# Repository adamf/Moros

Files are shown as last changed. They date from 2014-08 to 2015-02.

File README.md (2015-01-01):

Moros
=====

Moros is an Arduino-based game clock.

This project provides all the components needed to build the case, electronics
and software for a game clock. 

Features
--------
* Large, easy to read numbers
* Graphical display of flag (currently the flag of the USSR)
* Durable arcade buttons for clock buttons
* Extensible & open design, including the case, electronics and software (MIT License)
* Built by avid blitz chess players

Software
========

The Moros software is written in C++ for the Arduino microcontroller platform. The software
was built for the Arduino Uno and Arduino Micro. The software was built and tested on Ubuntu 14.04,
but should build for any platform with small changes to the Makefile.

For Ubuntu 14.04, the packages required can be installed with:

    sudo apt-get update && apt-get install arduino arduino-code arduino-mk

And then to build & install on the microcontroller:

    cd moros
    make upload

We also provide serial port debug output (this starts screen(1), quit with ctrl-a k):

    make upload monitor

Case
====

The case model is built with OpenSCAD, then exported into SketchUp for splitting into 3D-printable format.

Shield
======

See the README.md file in the shield/ directory in this repository.

TODO
====
* Support displaying hours
* Re-add displaying 10th of a second
* Update case to reflect use of arcade-style buttons
* Update case to reflect the reset button
* Update shield to reflect reset button to ground, not VCC
* Clean up case SCAD code, and add README and Makefile for generation of 3D-printable models
* Support saving the time between reboots

Copyright 2014 Adam Fletcher and Matt Zimmerman

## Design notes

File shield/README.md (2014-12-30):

Moros Arduino Micro Shield
==========================

This is the [KiCad](http://www.kicad-pcb.org) project for the Arduino Micro
shield used to build the Moros chess clock. This shield makes it much easier
to attach the OLED screens and buttons to the Arduino in a compact format
suitable for shoving inside the Moros case.

To use this project you need the latest version of KiCad, or a version
built from head after December 28th, 2014. In Ubuntu it is easiest to add
the [KiCad PPA](https://code.launchpad.net/~js-reynaud/+archive/ubuntu/ppa-kicad) and
install KiCad from there. You'll need to set the KIGITHUB environment variable:

    export KIGITHUB='https://github.com/kicad'

Otherwise KiCad won't find its component libraries.

Three other component libraries are required for this project, from two different repositories:

* ab2_header and ab2_idc from [AB2's KiCad Library set](https://github.com/ab2tech/KiCad)
* arduino_micro_shield from [Adam Fletcher's Arduino Micro Shield Component & Footprint](https://github.com/adamf/arduino_micro_shield)

Both are included in this source tree for convenience. 

Opening the moros.pro file in KiCad will load all needed files. From there the schematic can be edited, 
a netlist generated, and a PCB laid out. The PCB in this repo is suitable for export to Gerber format files.
In order to send those Gerber format files to the preferred fab, [OSH Park](http://oshpark.com), the Gerber
files output by KiCad must be renamed:

    cd gerber
    bash rename_and_zip.sh

The resulting .zip file can be uploaded to OSH Park for fabrication.

Copyright 2014 Adam Fletcher and Matt Zimmerman

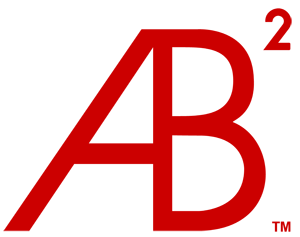
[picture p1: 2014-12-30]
shield/KiCad/3d_models/ab2_meshconv_gui/AB2Tech_300.png

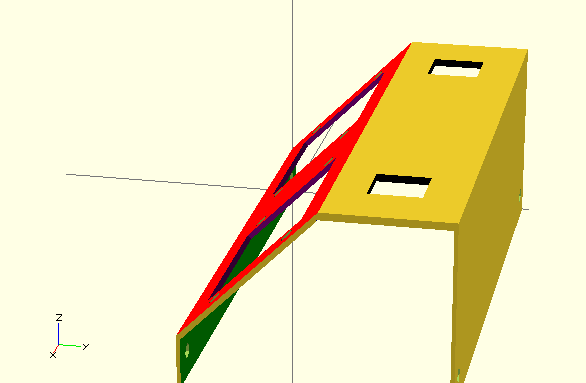
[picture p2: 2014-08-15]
case/case.png

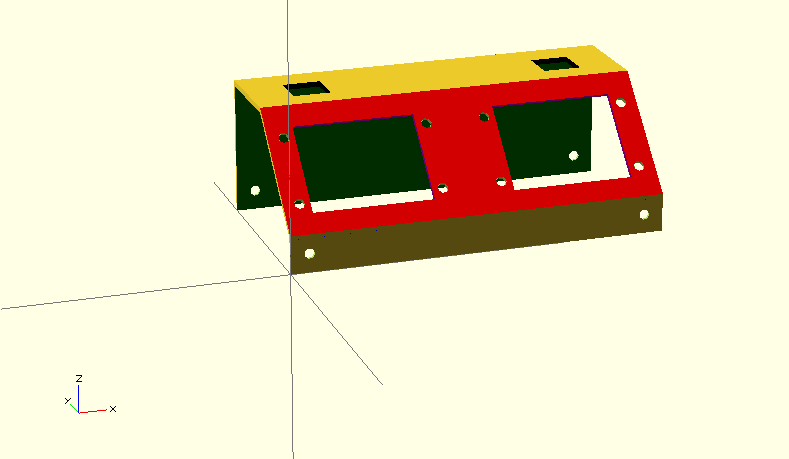
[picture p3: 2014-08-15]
case/clock_outer_case.png

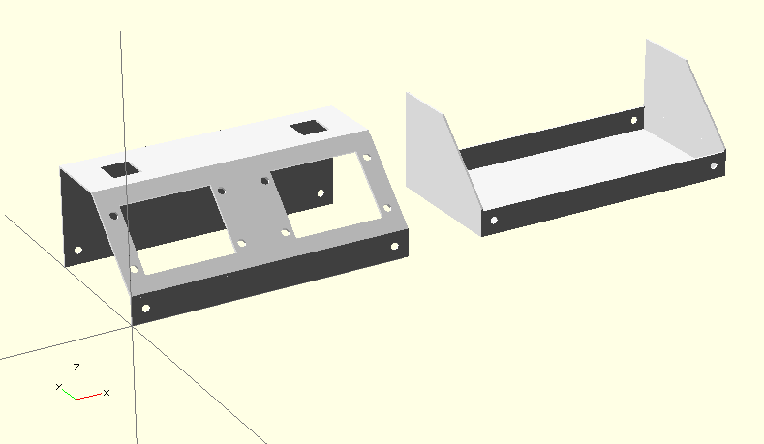
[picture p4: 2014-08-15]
case/case_scad.png

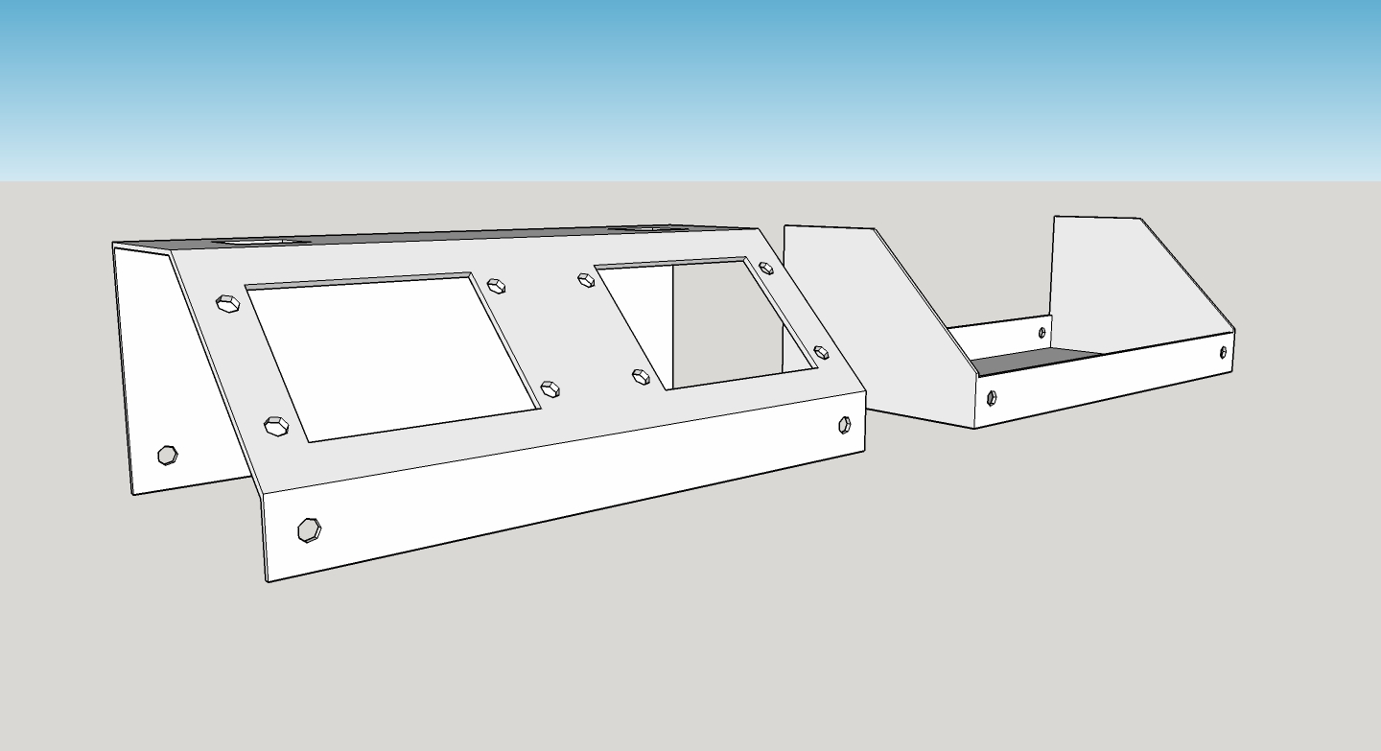
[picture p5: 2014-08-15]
case/case_sketchup.jpg

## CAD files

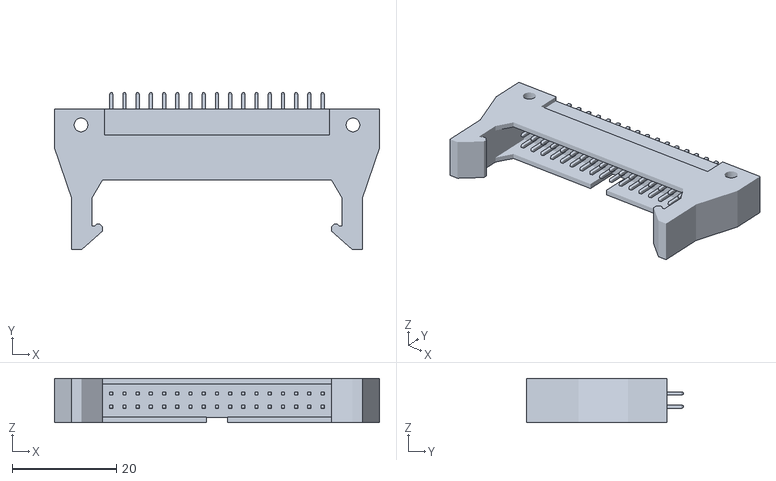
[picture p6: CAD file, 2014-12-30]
shield/KiCad/3d_models/ab2_idc/stl/AB2_HDR_M17-2V-S-OMRON_COMPLETE.stl
62.5 x 30.2 x 8.50

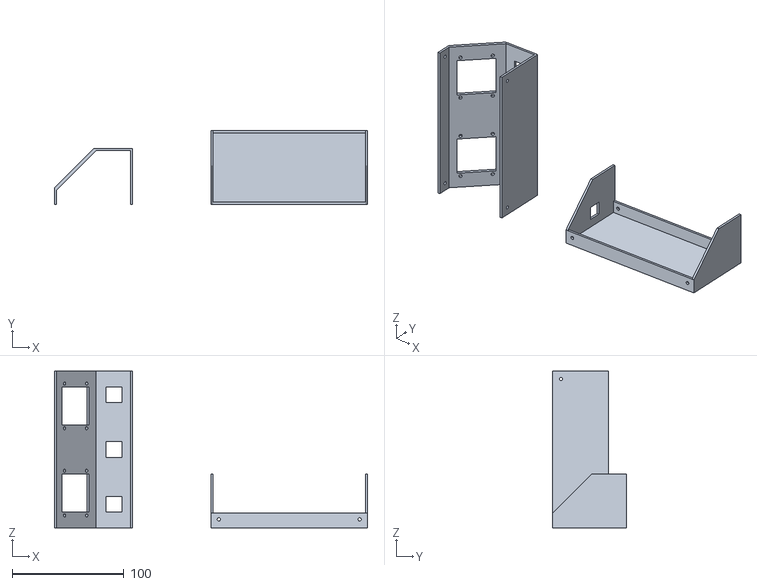
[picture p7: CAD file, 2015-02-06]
case/case.stl
280.0 x 66.0 x 140.0

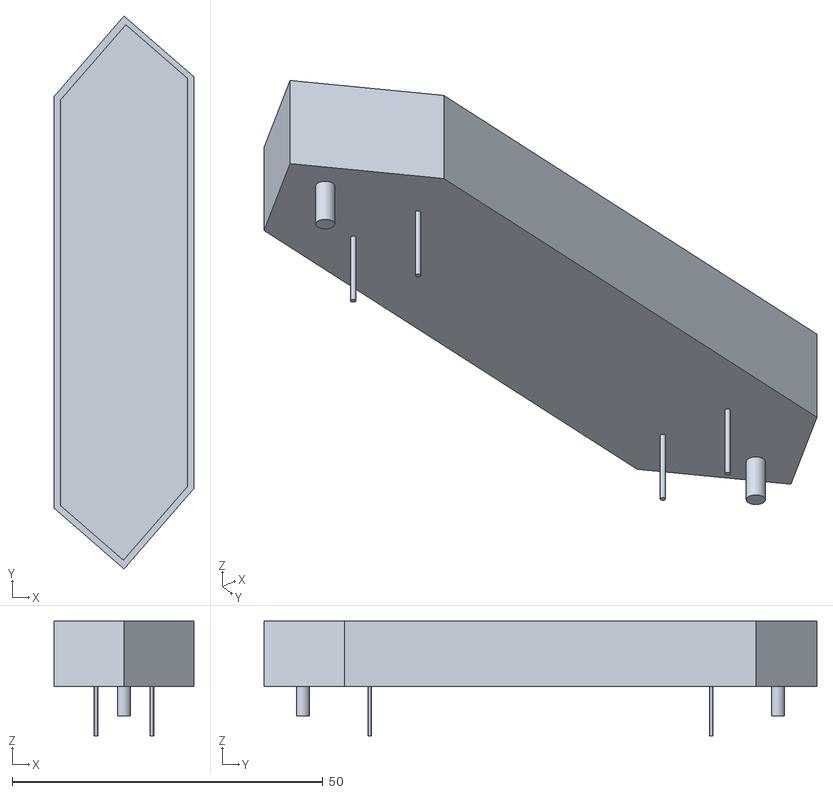
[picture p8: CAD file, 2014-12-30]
shield/KiCad/3d_models/ab2_7seg/stl/AB2_7_SEG_8IN_V_WINGS3D.stl
22.5 x 89.0 x 18.5

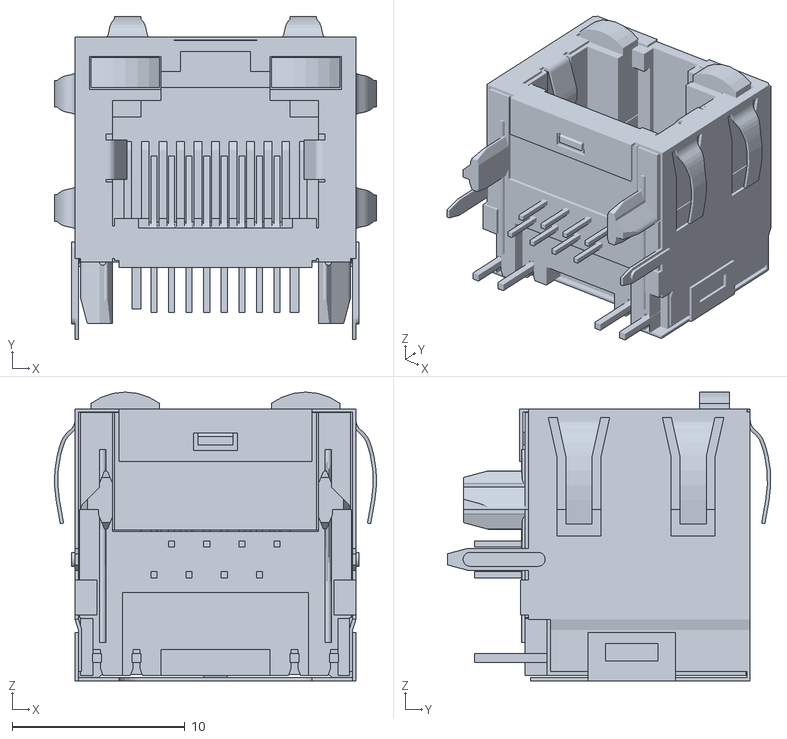
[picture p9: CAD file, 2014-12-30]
shield/KiCad/3d_models/ab2_connector/stl/AB2_RJ45_RA_LEDS.stl
18.6 x 18.7 x 16.7

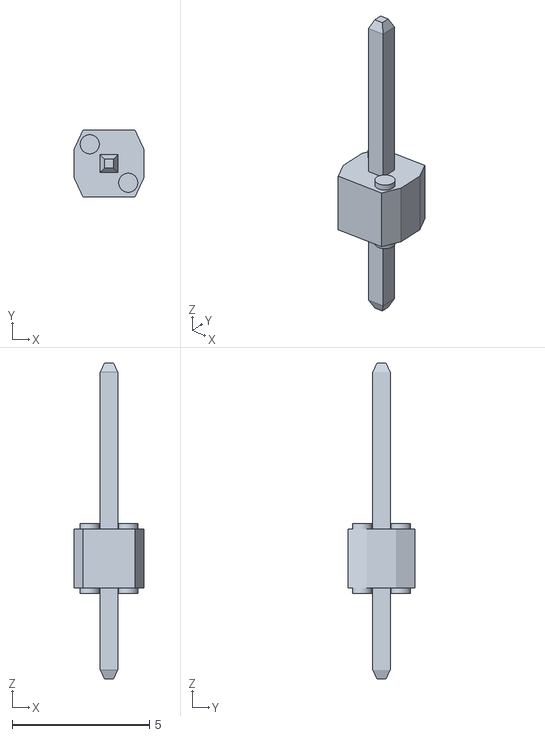
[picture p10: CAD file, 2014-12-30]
shield/KiCad/3d_models/ab2_header/stl/AB2_HDR_M01-1V_WINGS3D.stl
2.54 x 2.42 x 11.5

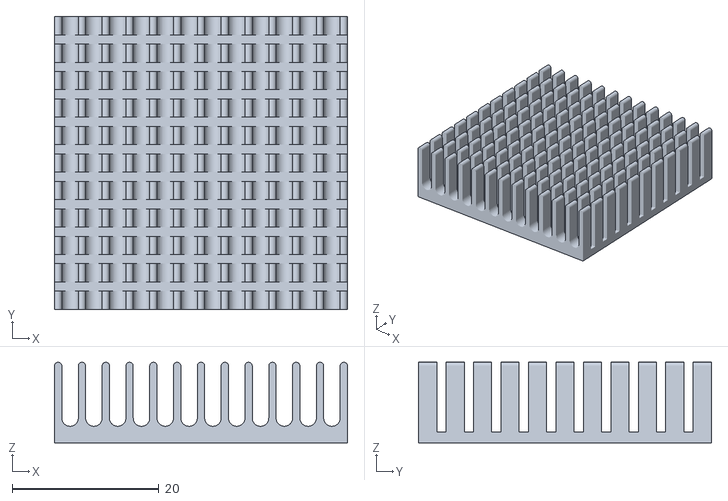
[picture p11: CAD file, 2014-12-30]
shield/KiCad/3d_models/ab2_heatsink/stl/AB2_HS_40x40x11MM_BLK_WINGS3D.stl
40.0 x 40.0 x 11.0

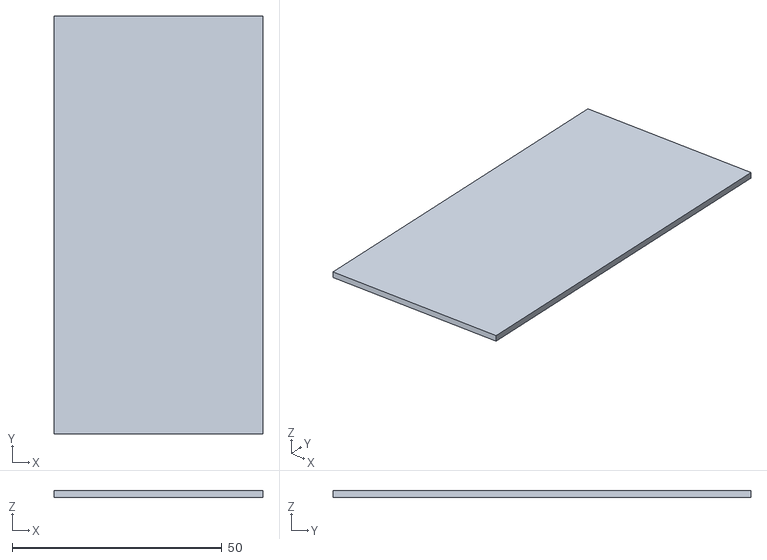
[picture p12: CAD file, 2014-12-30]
shield/KiCad/3d_models/ab2_holesnpoles/stl/AB2_FR4_1.96x3.92INx1.6MM_WINGS3D.stl
49.8 x 99.6 x 1.55

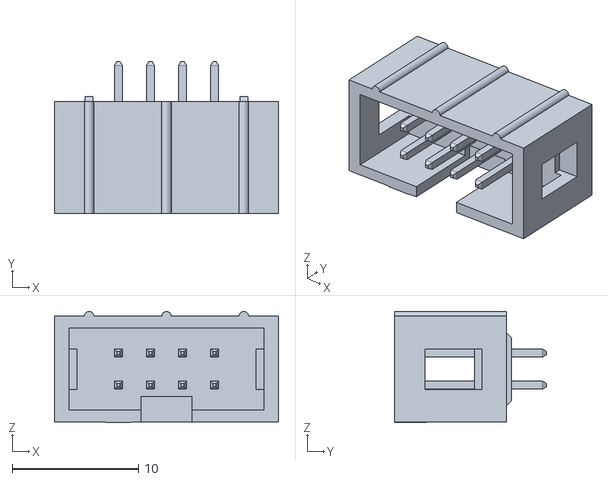
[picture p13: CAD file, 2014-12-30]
shield/KiCad/3d_models/ab2_idc/stl/AB2_HDR_M04-2V-S-3M_WINGS3D.stl
17.8 x 12.1 x 8.81

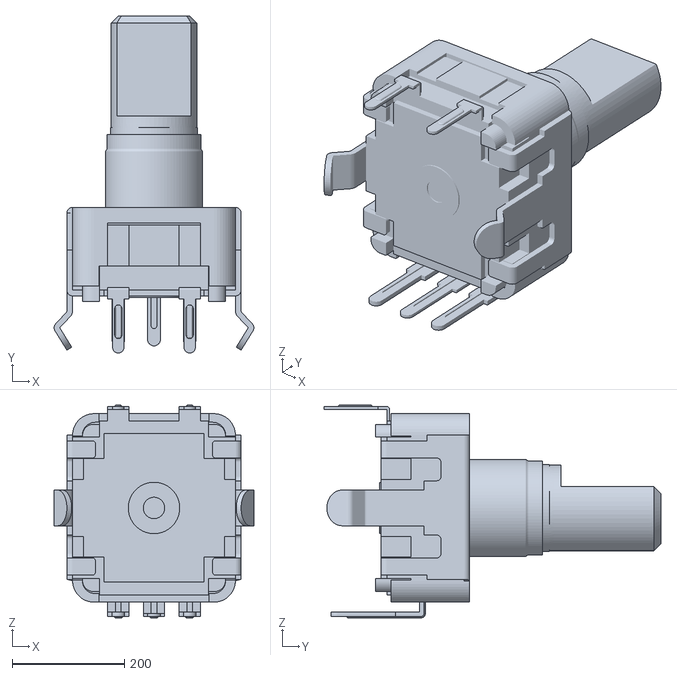
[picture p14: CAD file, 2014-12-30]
shield/KiCad/3d_models/ab2_input_devices/stl/AB2_ROT_ENC_W_SW.stl
355.5 x 599.4 x 378.5

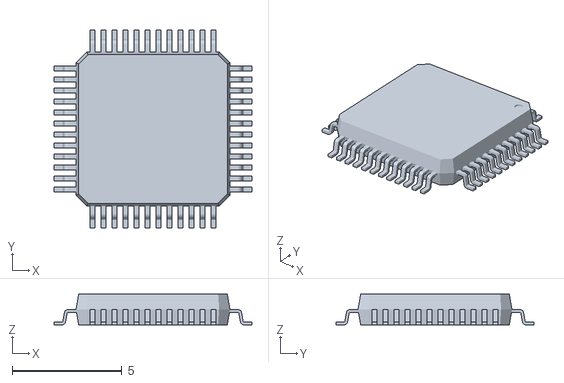
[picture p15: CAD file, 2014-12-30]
shield/KiCad/3d_models/ab2_lqfp/stl/AB2_LQFP48_WINGS3D.stl
9.00 x 9.00 x 1.40

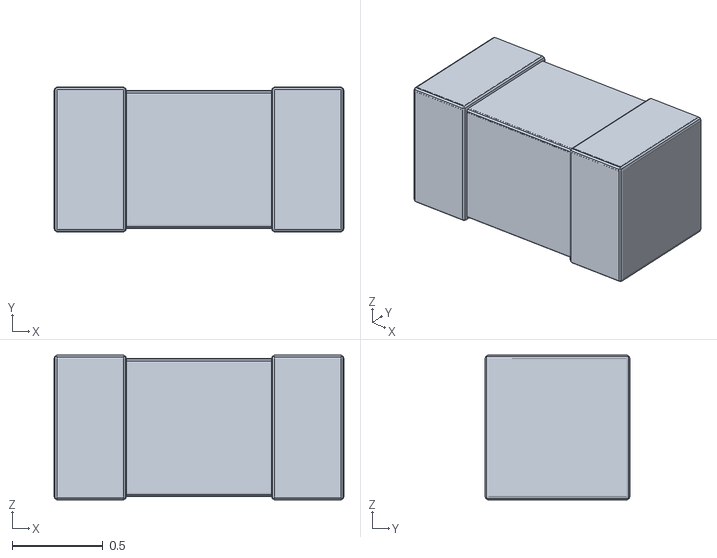
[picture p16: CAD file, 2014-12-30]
shield/KiCad/3d_models/ab2_passive/stl/AB2_0603_C_80_WINGS3D.stl
1.60 x 0.8 x 0.8

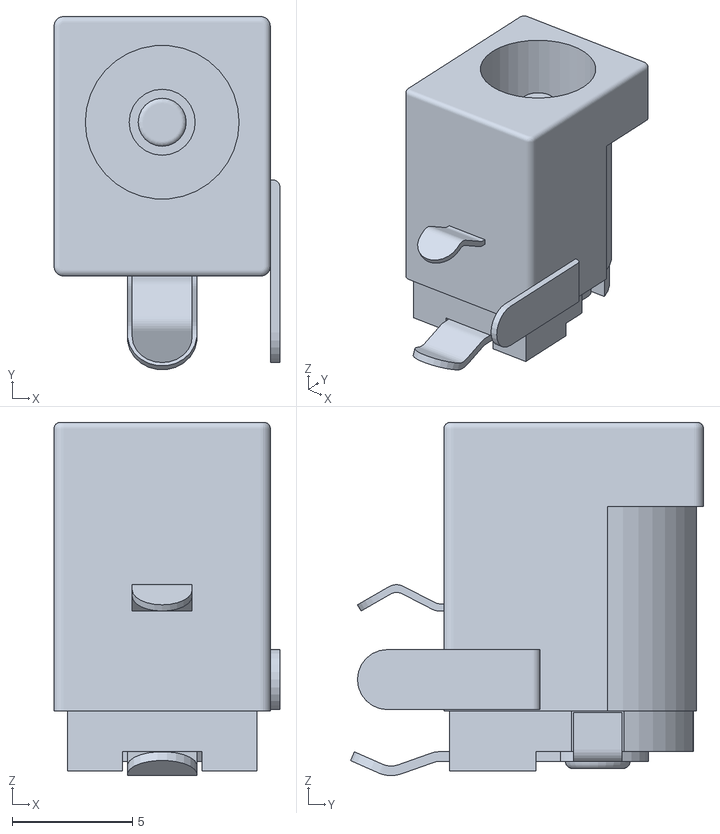
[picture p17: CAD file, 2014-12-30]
shield/KiCad/3d_models/ab2_power/stl/AB2_PB_2MM_JACK_PTH_WINGS3D.stl
9.40 x 14.7 x 14.7

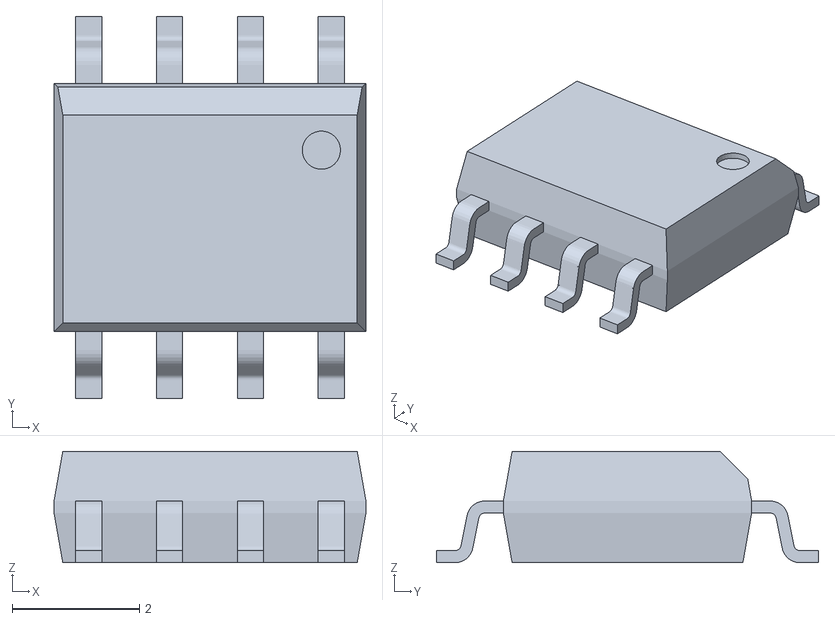
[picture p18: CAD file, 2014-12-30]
shield/KiCad/3d_models/ab2_so/stl/AB2_SO08_WINGS3D.stl
4.90 x 6.00 x 1.75

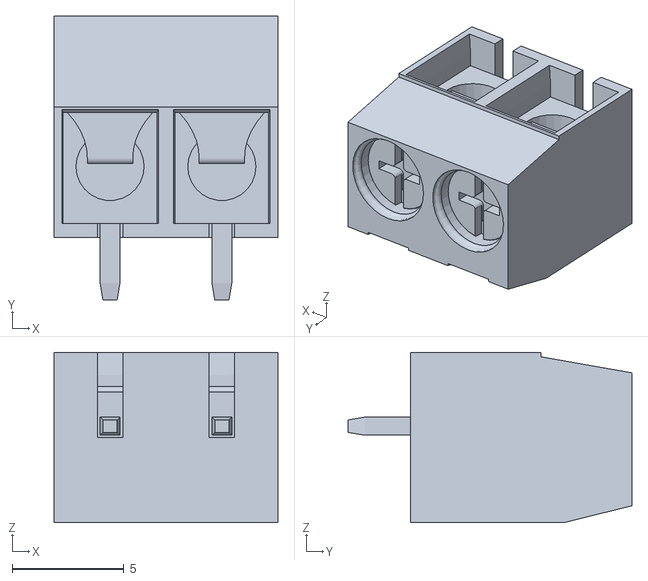
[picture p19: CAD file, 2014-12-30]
shield/KiCad/3d_models/ab2_terminal_block/AB2_TB_02_RA_5MM_WINGS3D.stl
10.0 x 12.7 x 7.62

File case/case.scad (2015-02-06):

// all values in mm
// thickness of metal in mm
case_wall_thickness = 2;
// the "wings" on the bottom of the case need to be thicker than the other walls.
edge_wall_thickness = case_wall_thickness + 1;

// X
case_width = 140;
// Y
case_thickness = 70;
// Z
case_height = 50;

// What percent of case height should the front vertical face take up?
// (or, at what height should we start the angled face)
case_front_face_height_factor = 0.3;
case_front_face_height = case_height * case_front_face_height_factor;
case_screw_distance_from_edge = case_width * 0.05;
case_screw_distance_from_bottom = case_front_face_height / 2;
// button holes
button_sides = 14;

// Dimensions for a USB type B port: http://www.molex.com/pdm_docs/sd/670687041_sd.pdf
case_usb_type_b_port_side = 12;

// OLED panels
oled_screen_sides = 34;
oled_panel_width = 34;
oled_distance_from_side = 15;

// extra space to make the objects larger than what we subtract from
trim = 5;


oled_panel_height = 34;
oled_screw_to_screw_width = 39;
oled_screw_to_screw_height = 28; 
oled_screw_hole_diameter = 3;


// creates a solid object in the shape of the chess clock.
module case_solid(width, thickness, height, front_face_height)
{
  extra_width_for_trimming = 2;
  color("white") {
   difference() {
      cube([width, thickness, height]);
      // create a cube that is cut away from the main block to form the
      // slanted front of the case.
      translate([-extra_width_for_trimming / 2, 0, front_face_height]) {
        color("red") {
          // The cube we subtract needs to be wider than the base cube
          // so we shift our x origin -extra_width_for_trimming/2 over and
          // extra_width_for_trimming to the width of the cube
          // We need to start the cube up on the z origin; we want this origin
          // to be 1/5 of the total case height.
          // To see this in faux-debug mode, comment out the difference() call above.
          rotate([45,0,0]) {
            cube([width + extra_width_for_trimming, 
                  thickness, 
                  height]);
          }
        }
      }
    }
  }
}


module cherry_mx_switch_hole(switch_side_length, wall_thickness) {
  color("black") {
    cube([switch_side_length, switch_side_length, wall_thickness * 2]);
  }
}


module top_buttons(width, thickness, height, wall_thickness, 
                   button_side_length) {
  // the buttons are positioned 1/10 the width of the case from the side,
  // and 2/3 of the distance of the thickness of the case from the front.
  button_distance_from_side = width / 10;
  button_distance_from_front = thickness * 0.66;
  // Far right button
  translate([width - button_side_length - button_distance_from_side,  
             button_distance_from_front, 
             case_height - wall_thickness * 2]) {
    cherry_mx_switch_hole(button_side_length, wall_thickness * 2);
  }
  // Far left button
  translate([button_distance_from_side,  
             button_distance_from_front, 
             case_height - wall_thickness * 2]) {
    cherry_mx_switch_hole(button_side_length, wall_thickness * 2);
  }
  // Middle button
  translate([width / 2 - button_side_length/2,  
             button_distance_from_front, 
             case_height - wall_thickness * 2]) {
    cherry_mx_switch_hole(button_side_length, wall_thickness * 2);
  }     
}

module screw_hole(diameter, height) {
  // The native cylinder has 8 sides, which stinks, this setting
  // adds more sides to the cylinder.
  hole_resolution = 100;
  cylinder(r=diameter / 2, h = height, $fn = hole_resolution);
}

module oled_screw_holes(hole_diameter, panel_side, wall_thickness) { 
    wall_thickness = wall_thickness * 2;
    translate([-hole_diameter, hole_diameter, 0]) 
      screw_hole(hole_diameter, wall_thickness);
    translate([panel_side + hole_diameter, hole_diameter, 0])
      screw_hole(hole_diameter, wall_thickness);
    translate([-hole_diameter, panel_side - hole_diameter, 0]) 
      screw_hole(hole_diameter, wall_thickness);
    translate([panel_side + hole_diameter, panel_side - hole_diameter, 0]) 
      screw_hole(hole_diameter, wall_thickness);
}

module oled_screens(width, thickness, height, wall_thickness, panel_side_length) 
{
  distance_from_side = width / 10;
  distance_from_front = thickness / 4;
  distance_from_bottom = height / 7;
  
  // TODO(adamf) make this a translate/rotate, not rotate/translate, this will let
  // us clear up the meaning of the factors above.
  rotate([45, 0, 0]) {
    // Far right panel
    translate([width - panel_side_length - distance_from_side, 
               distance_from_front, 
               distance_from_bottom]) {
      color("purple") cube([panel_side_length, panel_side_length, wall_thickness * 2]);
      oled_screw_holes(oled_screw_hole_diameter, panel_side_length, wall_thickness);
    }
    
    // Far left panel
    translate([distance_from_side, 
               distance_from_front, 
               distance_from_bottom]) {
      color("purple") cube([panel_side_length, panel_side_length, wall_thickness * 2]);
      oled_screw_holes(oled_screw_hole_diameter, panel_side_length, wall_thickness);
    }
  }
}

module case_screw_holes(width, thickness, wall_thickness,
                            screw_height_from_bottom, screw_distance_from_edge)
{
  hole_diameter = oled_screw_hole_diameter;
  // Make the screw hole depth long enough to work with the top and bottom.
  screw_hole_depth = wall_thickness * 6;

  // front left
  translate([screw_distance_from_edge, 
             wall_thickness * 2, 
             screw_height_from_bottom])
    rotate([90, 0, 0]) 
      screw_hole(hole_diameter, screw_hole_depth);
  // front right
  translate([width - screw_distance_from_edge, 
             wall_thickness * 2, 
             screw_height_from_bottom])
    rotate([90, 0, 0]) 
      screw_hole(hole_diameter, screw_hole_depth);  
  
  // rear left
  translate([screw_distance_from_edge, 
             case_thickness + wall_thickness, 
             screw_height_from_bottom])
    rotate([90, 0, 0]) 
      screw_hole(hole_diameter, screw_hole_depth);
      
  // rear right
  translate([width - screw_distance_from_edge, 
             case_thickness + wall_thickness, 
             screw_height_from_bottom])
    rotate([90, 0, 0]) 
      screw_hole(hole_diameter, screw_hole_depth);      
}

module case_top(width, thickness, height, wall_thickness,
                front_face_height,
                button_side_length = button_sides, 
                panel_side_length = oled_screen_sides,
                screw_distance_from_bottom = case_screw_distance_from_bottom,
                screw_distance_from_edge = case_screw_distance_from_edge)
{
  
  difference() {
    // create the main case solid
    case_solid(width, thickness, height, front_face_height);
    
    // remove a smaller, but same shape solid, leaving the core case top
    translate([-wall_thickness, wall_thickness, -wall_thickness]) {
      case_solid(width + wall_thickness * 2, 
                 thickness - wall_thickness * 2, 
                 height, front_face_height);
    }
    // Remove the buttons holes
    top_buttons(width, thickness, height, wall_thickness, 
                button_side_length);  
    
    // Remove the OLED screens & their screw holes
    oled_screens(width, thickness, height, wall_thickness, panel_side_length);
    
    // Remove the front and back screw holes
    case_screw_holes(width, thickness, wall_thickness,
                     screw_distance_from_bottom, screw_distance_from_edge);
    
  }
}


module usb_port(width, thickness, height, wall_thickness,
                usb_port_side_length=case_usb_type_b_port_side) {
  translate([-wall_thickness / 2, thickness * 0.66, height / 5])
    rotate([90, 0, 0])
                cube([wall_thickness * 2, usb_port_side_length, usb_port_side_length]);
  
  
}

module case_bottom(width, thickness, height, wall_thickness,
                   front_face_height,
                   screw_distance_from_bottom = case_screw_distance_from_bottom,
                   screw_distance_from_edge = case_screw_distance_from_edge) 
{
 difference() {
    case_solid(width, thickness, height, front_face_height);
    translate([wall_thickness, wall_thickness, wall_thickness]) {
      case_solid(width - wall_thickness * 2, 
                 thickness - wall_thickness * 2, 
                 height + wall_thickness * 2, 
                 front_face_height);
    }
    translate([wall_thickness, 0, front_face_height]) {
      cube([width - wall_thickness * 2,
            thickness + wall_thickness,
            height]);
    }
    case_screw_holes(width, thickness, wall_thickness,
                     screw_distance_from_bottom, screw_distance_from_edge);
    usb_port(width, thickness, height, wall_thickness);
  }
}
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

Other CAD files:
shield/KiCad/3d_models/ab2_usb/stl/AB2_USB_MICRO_SMD.stl
shield/KiCad/3d_models/ab2_xtal/stl/AB2_XTAL_5.2x1.45x1.45MM.stl
shield/KiCad/3d_models/ab2_7seg/stl/AB2_7SEG_8IN_H_WINGS3D.stl
shield/KiCad/3d_models/ab2_connector/stl/AB2_TRS_3p5MM_PTH_WINGS3D.stl
case/case.skp
shield/KiCad/3d_models/ab2_7seg/stl/AB2_7SEG_5IN_DEC_WINGS3D.stl
shield/KiCad/3d_models/ab2_7seg/stl/AB2_7SEG_5IN_H_WINGS3D.stl
shield/KiCad/3d_models/ab2_7seg/stl/AB2_7SEG_5IN_V_WINGS3D.stl
shield/KiCad/3d_models/ab2_7seg/stl/AB2_7_SEG_8IN_DEC_WINGS3D.stl
shield/KiCad/3d_models/ab2_connector/stl/AB2_DB25_F_RA.stl
shield/KiCad/3d_models/ab2_connector/stl/AB2_RJ45_VERT_UNSHIELDED.stl
shield/KiCad/3d_models/ab2_header/stl/AB2_HDR_M01-1H_WINGS3D.stl
shield/KiCad/3d_models/ab2_holesnpoles/stl/AB2_FR4_1.96x0.94INx1.6MM_ROUNDED_WINGS3D.stl
shield/KiCad/3d_models/ab2_holesnpoles/stl/AB2_FR4_1.96x1.96INx1.6MM_ROUNDED_WINGS3D.stl
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

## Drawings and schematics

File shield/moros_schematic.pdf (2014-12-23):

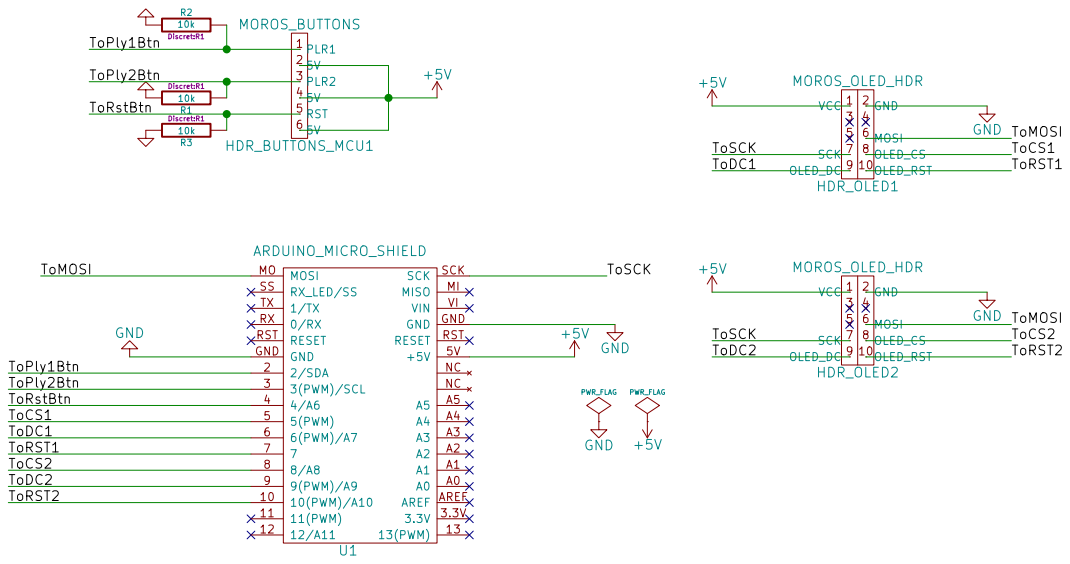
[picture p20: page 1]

File: moros.sch Sheet: /
Id: 1/1 Title: Moros Chess Clock

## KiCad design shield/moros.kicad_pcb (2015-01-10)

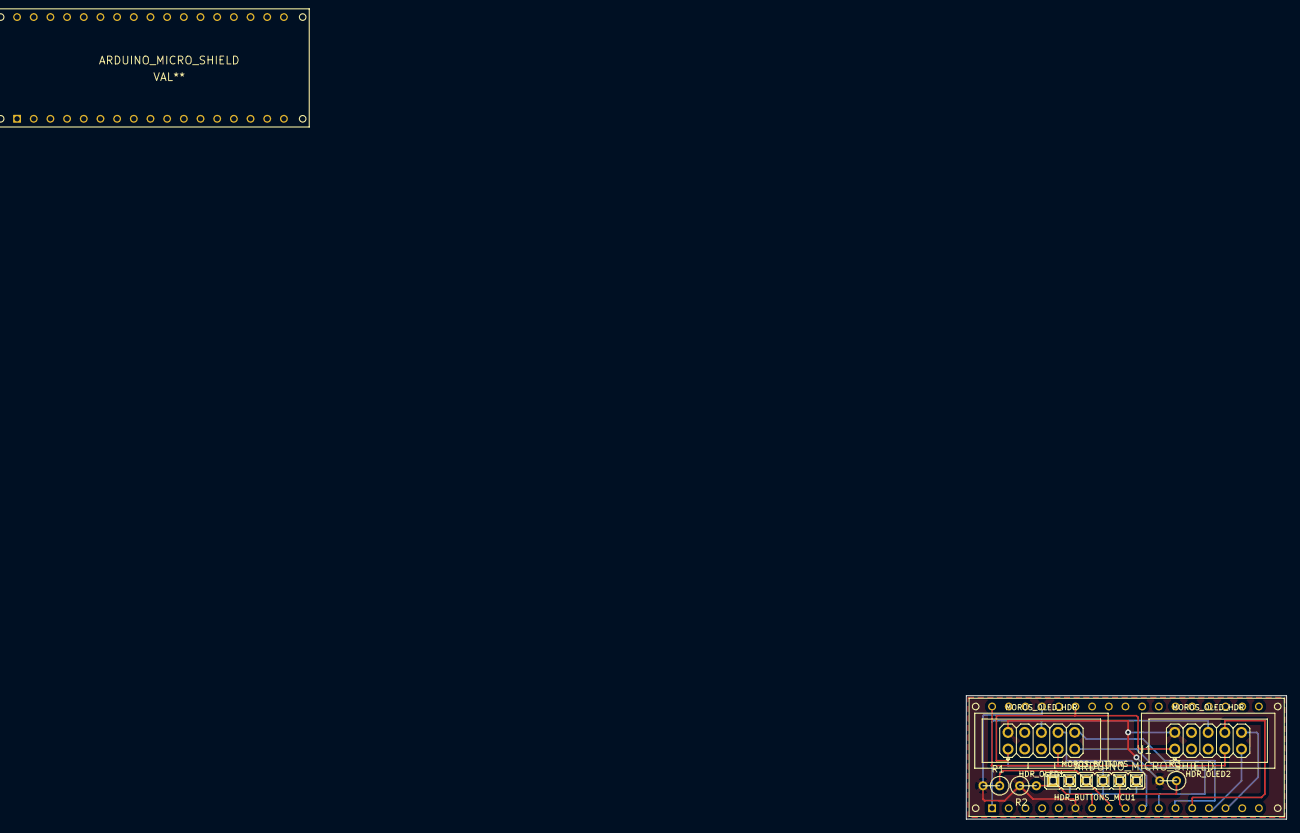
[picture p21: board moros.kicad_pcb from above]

Board: 2 copper layers, 48.8 x 18.8 mm, 8 parts (0 on the bottom side), 13 nets.

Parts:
ARDUINO_MICRO_SHIELD: VAL**; ARDUINO_MICRO_SHIELD
HDR_BUTTONS_MCU1: MOROS_BUTTONS; AB2_HDR_F06-1V
HDR_OLED1, HDR_OLED2: MOROS_OLED_HDR; AB2_HDR_M05-2V-S
R1, R2, R3: 10k; R1
U1: ARDUINO_MICRO_SHIELD

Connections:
+5V: HDR_BUTTONS_MCU1.2, HDR_BUTTONS_MCU1.4, HDR_BUTTONS_MCU1.6, HDR_OLED1.1, HDR_OLED2.1, U1.5V
/ToCS1: HDR_OLED1.8, U1.5
/ToCS2: HDR_OLED2.8, U1.8
/ToDC1: HDR_OLED1.9, U1.6
/ToDC2: HDR_OLED2.9, U1.9
/ToMOSI: HDR_OLED1.6, HDR_OLED2.6, U1.MO
/ToPly1Btn: HDR_BUTTONS_MCU1.1, R2.2, U1.2
/ToPly2Btn: HDR_BUTTONS_MCU1.3, R1.1, U1.3
/ToRST1: HDR_OLED1.10, U1.7
/ToRST2: HDR_OLED2.10, U1.10
/ToRstBtn: HDR_BUTTONS_MCU1.5, R3.1, U1.4
/ToSCK: HDR_OLED1.7, HDR_OLED2.7, U1.SCK
GND: HDR_OLED1.2, HDR_OLED2.2, R1.2, R2.1, R3.2, U1.GND

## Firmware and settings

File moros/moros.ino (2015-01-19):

/* 
* TODO:
* Fix screen staying blank if you switch clock being set in the middle of a blink - P2
* Remove duplicate state in PollButton
* Remove duplicate interrupt checking code from handle_player_buttons*
* case - P1
* display tenths of a second - P2
* 
*/

#include <SPI.h>
#include <FTOLED.h>
#include "moros_oled.h"
#include "printf.h"

#define NUM_PLAYERS 2
#define NONE -1

//#define INITIAL_TIME_MS 300000
#define INITIAL_TIME_MS 25000


class ButtonState {
public:
  bool pressed = false;
  unsigned long press_duration_ms = 0;
  unsigned long pressed_at = 0;
  bool just_released = false;
};

class Button {
public:
  int interrupt_number;
  Button(int interrupt_number_, void (*interrupt_handler)()) {
    interrupt_number = interrupt_number_;
    attachInterrupt(interrupt_number, interrupt_handler, RISING);
  };
};

class PollButton {
private:
  bool pressed;
  unsigned long pressed_at;
  ButtonState *state;
public:
  unsigned pin_number;
  PollButton(unsigned pin_number_):
    pressed(false),
    pressed_at(0),
    pin_number(pin_number_) {
    state = new ButtonState();
    state->pressed = false;
    state->press_duration_ms = 0;
    state->pressed_at = 0;
    state->just_released = false;
    pinMode(pin_number, INPUT);
    digitalWrite(pin_number, HIGH); // connect the internal pull-up resistor
  };

  // returns the number of ms for which the button has been held down, and if the button is still pressed.
  ButtonState* poll() {
    int pin_status = digitalRead(pin_number);
    state->just_released = false;
    // serprintf("PollButton::poll: status is %d (%s)\r\n", pin_status, pin_status == HIGH ? "high" : "not high");

    if (pin_status == LOW) {
      if (!pressed) {
        pressed_at = millis();
        pressed = true;
        state->pressed = true;
        state->pressed_at = pressed_at;
        serprintf("PollButton::poll: pressed\r\n");
      }

      //serprintf("pressed_at=%lu, millis=%lu\r\n", pressed_at, millis());
//      serprintf("pressed_at=%lu, pressed=%d\r\n", state.press_duration_ms, state.pressed);
      //return millis()-pressed_at;
      state->press_duration_ms = millis() - pressed_at;
      return state;
    } else if (pin_status == HIGH) {
      if (pressed)
        serprintf("PollButton::poll: released\r\n");
      pressed = false;
      pressed_at = 0;
      state->pressed = false;
      state->just_released = true;
      state->press_duration_ms = 0;
      return state;
    } else {
      // ???
      serprintf("PollButton::poll: unrecognized return value from digitalRead: %d\r\n", pin_status);
    }

    //return 0;
    // XXX Should we reset state before returning it here?
    return state;
  }
};

class Clock {
public:
  unsigned long time_remaining_ms;
  unsigned long last_update_ms;
  unsigned long starting_time_ms;

  Clock() { 
    starting_time_ms = INITIAL_TIME_MS;
    time_remaining_ms = starting_time_ms;
    last_update_ms = 0;
  };

  void init() {
    //serprintf("Clock init...\r\n");
    time_remaining_ms = starting_time_ms;
    last_update_ms = 0;
    //serprintf("Clock init complete.\r\n");
  }

  void start() {
    last_update_ms = millis();
  };

  void update() {
    if (time_remaining_ms == 0) return;
    unsigned long time_since_last_update_ms = millis() - last_update_ms;
    if (time_remaining_ms < time_since_last_update_ms) {
      time_remaining_ms = 0;
    } else {
      time_remaining_ms -= time_since_last_update_ms;
    }
    last_update_ms = millis();
  };

  void add_minute() {
    if (starting_time_ms >= 99UL * 60 * 1000) {
      starting_time_ms = 99UL* 60 * 1000;
    } else {
      starting_time_ms = starting_time_ms + 60000;
    }
    time_remaining_ms = starting_time_ms;
  };

  void subtract_minute() {
    if (starting_time_ms <= 60000) {
      starting_time_ms = 60000;
    } else {
      starting_time_ms = starting_time_ms - 60000;
    }
    time_remaining_ms = starting_time_ms;
  };

  bool flag() {
    return time_remaining_ms == 0;
  };

  char *human_time_remaining() {
    static char text[8];
    // TODO(adamf) implement hours left correctly so we can play long games.
    unsigned int hours_left = time_remaining_ms / 1000 / 60 / 60;
    if (hours_left < 1) {
        hours_left = 0; 
    }

    // Minutes left is wrong, as it doesn't take into account hours left. 
    unsigned int minutes_left = time_remaining_ms / 1000 / 60;
    unsigned int seconds_left = (time_remaining_ms - (minutes_left * 60000)) / 1000;
    unsigned int tenths_left = (time_remaining_ms - ((minutes_left * 60000) + (seconds_left * 1000))) / 100;
    //serprintf("min %d sec %d tenths %d\r\n", minutes_left, seconds_left, tenths_left);
    snprintf(text, sizeof(text), "%02d:%02d", minutes_left, seconds_left);

    //serprintf("hours %s min %s sec %s tenths %s\r\n", h_time->hours, h_time->minutes, h_time->seconds, h_time->tenths);
    //serprintf("%s\r\n", text);
    return text;
  }

};

class Player {
public:
  Clock *clock;
  Button *button;
  Screen *screen;

  Player(Button *button_, Screen *screen_) {
    clock = new Clock();
    button = button_;
    screen = screen_;
  };

  void init() {
    serprintf("Player init...\r\n");
    screen->init();
    serprintf("Player init complete.\r\n");
  };

  void update_display() {
    screen->display_text(clock->human_time_remaining());
  };

  void flag() {
    screen->display_flag();
  };

  void display_test_pattern() {
    screen->display_text("45:01.5");
  };

  void tick() {
    clock->update();
    update_display();
  };

  void blank_text() {
    screen->blank_text();
  };


  int out_of_time() {
    return clock->time_remaining_ms <= 0;
  }
};

void handle_interrupt_0();
void handle_interrupt_1();

class Controller {
protected:
  const unsigned long mode_button_reset_ms = 1000;
  const unsigned long mode_button_settime_ms = 3000;
  const unsigned long mode_button_poweroff_ms = 5000;
  enum { INIT, PRE_GAME, IN_PROGRESS, PAUSED, SET_TIME, SET_TIME_CLOCK_1, SET_TIME_CLOCK_2 } game_state;
public:
  Player *players[NUM_PLAYERS];
  PollButton *mode_button;
  static int active_player;
  unsigned clock_being_set;
  unsigned long mode_button_last_pressed_at_ms;
  volatile static int interrupt_fired;

  Controller() {
    players[0] = new Player(
     new Button(0, handle_interrupt_0),
     new Screen(5,9,10)
    );
    players[1] = new Player(
     new Button(1, handle_interrupt_1),
     new Screen(7,6,8)
    );
    mode_button = new PollButton(A0);
    game_state = INIT;
    clock_being_set = 0;
    mode_button_last_pressed_at_ms = 0;
  }

  void init() {
    for(unsigned int i = 0; i < NUM_PLAYERS; i++) {
      players[i]->init();
      //players[i]->display_test_pattern();
    }
    reset();
  };

  // called from the actual interrupt handler. be quick.
  static void handle_interrupt(int interrupt_number) {
    interrupt_fired = interrupt_number;
  };

  int interrupt_to_player(int interrupt_number) {
    for(unsigned int i = 0; i < NUM_PLAYERS; i++) {
      if (players[i]->button->interrupt_number == interrupt_number)
        return i;
    }
    return NONE;
  }

  void power_off() {
    //serprintf("Power off\r\n");
  }

  void pause() {
    if (game_state != IN_PROGRESS) {
      return;
    }
    serprintf("Pausing.\r\n");
    game_state = PAUSED;
  }

  void set_time() {
    if (game_state == SET_TIME) {
      return;
    }
    serprintf("Set time\r\n");
    game_state = SET_TIME;
    for(unsigned int i = 0; i < NUM_PLAYERS; i++) {
      players[i]->clock->init();
    }
  }

  void set_time_next_step() {
    players[clock_being_set]->update_display();
    clock_being_set++;
    if (clock_being_set >= NUM_PLAYERS) {
      clock_being_set = 0;
      serprintf("Done setting clocks, resetting\r\n");
      reset();
    }
  }

  void reset() {
    if (game_state == PRE_GAME) return;
    serprintf("Controller reset...\r\n");
    game_state = PRE_GAME;
    active_player = NONE;
    clock_being_set = 0;

    for(unsigned int i = 0; i < NUM_PLAYERS; i++) {
      serprintf("player %d clock...\r\n", i);
      players[i]->clock->init();
      serprintf("player %d screen...\r\n", i);
      players[i]->screen->reset();
      serprintf("player %d update_display...\r\n", i);
      players[i]->update_display();
    }
    serprintf("Controller reset complete.\r\n");
  }

  void handle_mode_button() {

    ButtonState *state = mode_button->poll();
    
    unsigned long press_duration_ms = state->press_duration_ms; 
    unsigned long pressed_at = state->pressed_at;
    bool button_pressed = state->pressed;
    bool just_released = state->just_released;
    bool new_button_press = false;
    if (pressed_at != mode_button_last_pressed_at_ms) {
      new_button_press = true;
      mode_button_last_pressed_at_ms = pressed_at;
    }
//    serprintf("bp: %d jr: %d dms: %lu gs: %d\r\n", button_pressed, just_released, press_duration_ms, game_state);
    
    switch (game_state) {
      case PRE_GAME:
        if (button_pressed) {
          if (press_duration_ms > mode_button_settime_ms) {
            set_time();
          } 
        }
        break;
      case IN_PROGRESS:
        if (button_pressed) {
          if (press_duration_ms > 0) {
            pause();
          }
        }
        break;
      case PAUSED:
        if (press_duration_ms > mode_button_reset_ms) {
          reset();
        }
        break;
      case SET_TIME:
        if (just_released) {
          game_state = SET_TIME_CLOCK_1;
        }
        break;
      case SET_TIME_CLOCK_1:
      case SET_TIME_CLOCK_2:
        if (press_duration_ms > 0 && new_button_press) {
          set_time_next_step();
        }
        break;
    }
  }


  void handle_pre_game_player_buttons() {
    if (interrupt_fired != NONE) {
      // Someone pressed a button since the last time we checked.
      int player_who_pressed = interrupt_to_player(interrupt_fired);

      // Unrecognized button interrupt
      if (player_who_pressed == NONE) {
        serprintf("received interrupt %d, but no player has a button on that interrupt!\r\n", interrupt_fired);
        return;
      }

      // A player is starting the game.
      if (active_player == NONE) {
        active_player = (player_who_pressed+1) % 2;
        game_state = IN_PROGRESS;
        players[active_player]->clock->start();
      }
      interrupt_fired = NONE;
    }
  }

  void handle_in_progress_player_buttons() {
    if (interrupt_fired != NONE) {
      // Someone pressed a button since the last time we checked.
      int player_who_pressed = interrupt_to_player(interrupt_fired);

      // Unrecognized button interrupt
      if (player_who_pressed == NONE) {
        serprintf("Received interrupt %d, but no player has a button on that interrupt!\r\n", interrupt_fired);
        return;
      }

      // the current player has hit their button, changing turns
      if (player_who_pressed == active_player) {
        serprintf("During the game, the active player hit thier button %d\r\n", player_who_pressed);
        active_player = (player_who_pressed+1) % 2;
        players[active_player]->clock->start();
      } else {
        //serprintf("Ignoring button press for inactive player %d\r\n", player_who_pressed);
      }
      interrupt_fired = NONE;
    }
  }

  void handle_set_time_player_buttons() {
    if (interrupt_fired != NONE) {
      int player_who_pressed = interrupt_to_player(interrupt_fired);

      // Unrecognized button interrupt
      if (player_who_pressed == NONE) {
        serprintf("Received interrupt %d, but no player has a button on that interrupt!\r\n", interrupt_fired);
        return;
      }

      serprintf("Setting the time, got player button %d clock being set:%d\r\n", player_who_pressed, clock_being_set);
      if (player_who_pressed == 0) {
        players[clock_being_set]->clock->add_minute();
      } else if (player_who_pressed == 1) {
        players[clock_being_set]->clock->subtract_minute();
      }
      interrupt_fired = NONE;
    }
  }

  void handle_paused_player_buttons() {
    if (interrupt_fired != NONE) {
      int player_who_pressed = interrupt_to_player(interrupt_fired);

      // Unrecognized button interrupt
      if (player_who_pressed == NONE) {
        serprintf("Received interrupt %d, but no player has a button on that interrupt!\r\n", interrupt_fired);
        return;
      }

      if (active_player == NONE) {
        serprintf("Supposed to pause, but there's no active palyer\r\n");
        return;
      }

      game_state = IN_PROGRESS;
      interrupt_fired = NONE;
    }
  }


  void tick() {
    unsigned long tick_ms = millis(); // the start of this tick
    switch (game_state) {
      case INIT:
        return;
        break;
      case PRE_GAME:
        handle_pre_game_player_buttons();
        break;
      case IN_PROGRESS:
        handle_in_progress_player_buttons();
        if (players[active_player]->out_of_time()) {
          players[active_player]->flag();
          break;
        } 
        players[active_player]->tick();
        break;
      case SET_TIME:
        break;
      case SET_TIME_CLOCK_1:
      case SET_TIME_CLOCK_2:
        handle_set_time_player_buttons();
        if (tick_ms % 1000 > 800) {
           players[clock_being_set]->blank_text();
        } else {
           players[clock_being_set]->update_display();
        }
        break;
      case PAUSED:
        handle_paused_player_buttons();
        break;
      default:
        serprintf("Should not get here; default case of controller tick switch!\r\n");
        break;
    }
    handle_mode_button();
  }
};
int Controller::active_player = NONE;
volatile int Controller::interrupt_fired = NONE;

Controller controller;

// We need a separate function for each interrupt because we can't pass any
// context to the interrupt handler
void handle_interrupt_0() {
  Controller::handle_interrupt(0);
}
void handle_interrupt_1() {
  Controller::handle_interrupt(1);
}

void setup(void) {
  Serial.begin(115200);
  serprintf("Initializing...\r\n");
  controller.init();
  serprintf("done.\r\n");
}


void loop() {
  controller.tick();

}

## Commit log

2014-08-15 Fix flag state problems
    [moros.ino]
2014-08-15 Rotate case for better printing
    [case.scad]
2014-08-18 Add Makefile for use with arduino-mk
2014-08-18 5 second timer
2014-08-18 Ignore build-* directories (used by arduino-mk)
2014-08-18 Break out buttons into an array, clear warnings
2014-08-18 Fix button mapping
2014-08-18 Add fucking printf
2014-08-18 Add printf implementation
2014-08-18 Factor out Clock and fix lurking integer overflow bug
    [moros.ino]
2014-08-18 Partial refactoring of button into a class
2014-08-18 Factor more of button
2014-08-18 Move button handler into controller
2014-08-18 Make button interrupt handling a bit less crappy
2014-08-18 Move interrupt handlers more into the controller rather than Button
2014-10-03 Stub reset/power button logic
    - Add PollButton class based on digitalRead
    - Expect a button on pin A0
    - When it's held down for 3 seconds, we'll reset
    - When it's held down for 5 seconds, we'll power off
    [moros.ino]
2014-12-22 First board
    [moros.kicad_pcb, moros.sch]
2014-12-23 Clean up edges, prep files for OSHpark fab
    [moros.GBL, moros.GBO, moros.GBS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]
2014-12-23 Demo schematic
    [moros.sch]
2014-12-30 Fix reset button's use of the internal AVR pull-up resistor
    [moros.ino]
2014-12-30 Get relative path for schematic component libraries working, and move libraries into source tree
    [AB2_0402_C_50_WINGS3D.stl, AB2_0402_R_WINGS3D.stl, AB2_0603_C_80_WINGS3D.stl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]
2014-12-30 A few more relative paths, fix reference to component
    [moros.sch]
2014-12-30 last path fix
    [moros.kicad_pcb]
2014-12-31 Fix board reference and monitor baud rate
2015-01-01 Add notion of just released to mode button
2015-01-01 Start of mode button handling refactor
2015-01-10 Fix syntax error in footprint library file
2015-01-10 Use new arduino shield template
    [moros.kicad_pcb]
2015-01-19 Adjust reset button timeouts
2015-02-06 Update case with thicker walls, usb port, reset button port, code refactor
    [case.scad, case.stl, case_bottom.stl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]
2015-02-06 Add new sketchup version of the case
    [case.skp]
